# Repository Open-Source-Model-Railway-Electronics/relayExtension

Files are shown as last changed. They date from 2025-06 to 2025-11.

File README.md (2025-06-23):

# Relay Extension

These are general-purpose relay modules for use with DCC decoders like the [OS-Solenoid-Decoder](https://github.com/Open-Source-Model-Railway-Electronics/OS-Solenoid-Decoder).

## Variants

### SMD Version
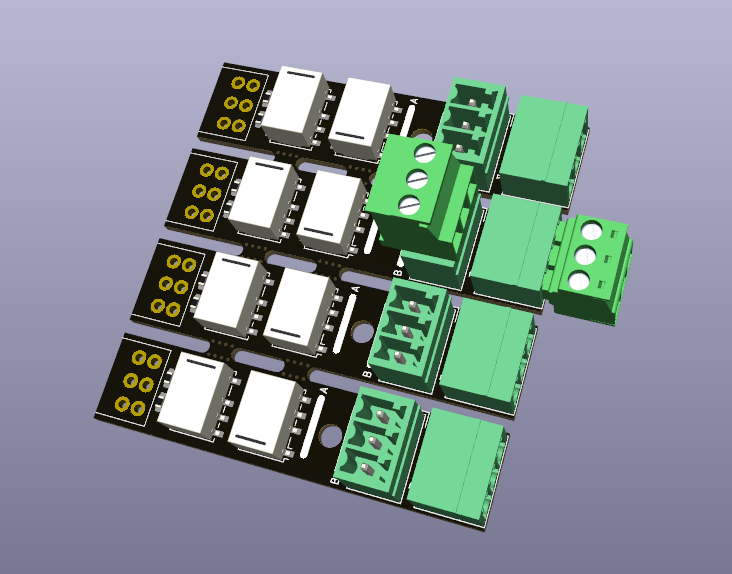
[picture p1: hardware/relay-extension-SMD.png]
SMD Relay Extension


### THT Version
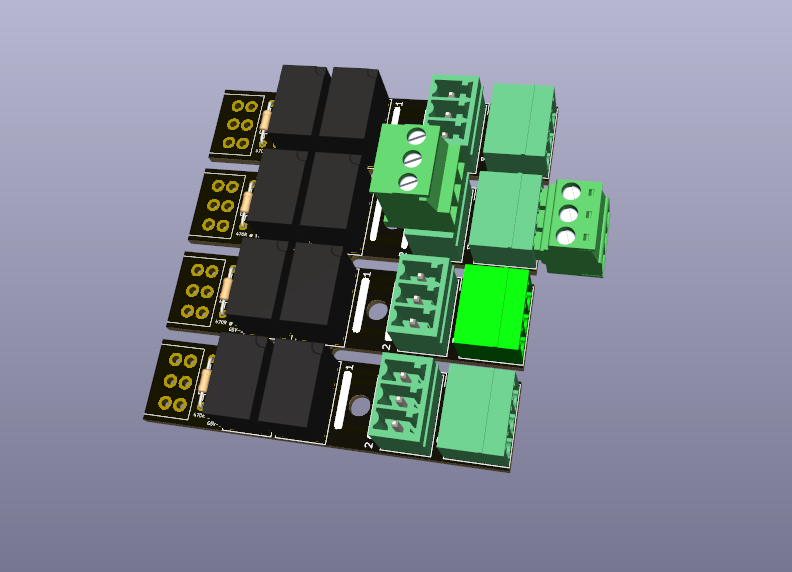
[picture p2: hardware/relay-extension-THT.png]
THT Relay Extension


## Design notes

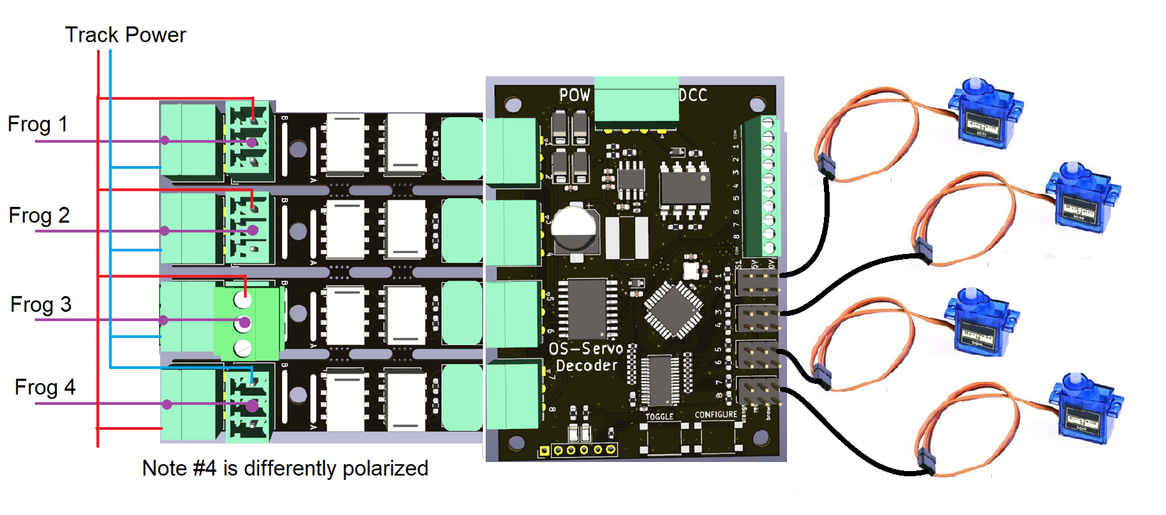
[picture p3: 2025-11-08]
docs/GP_relay_as_elekro_frog_servo.png

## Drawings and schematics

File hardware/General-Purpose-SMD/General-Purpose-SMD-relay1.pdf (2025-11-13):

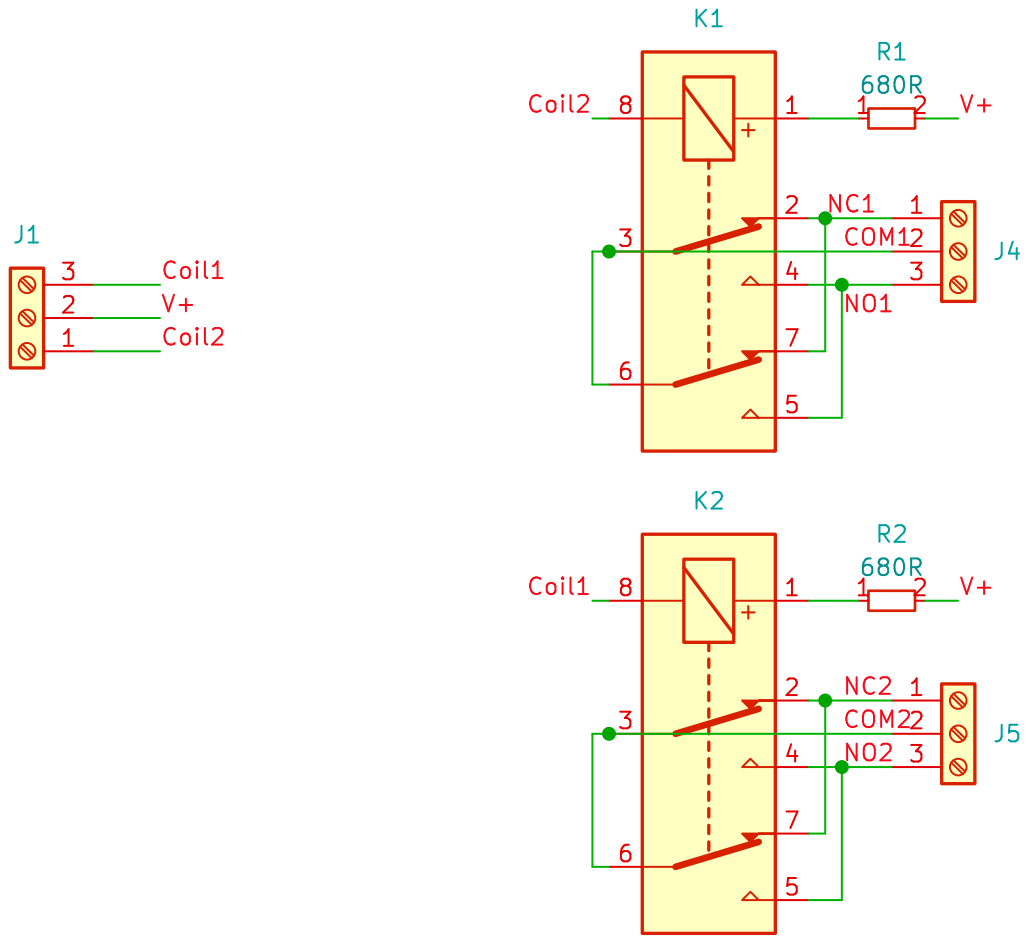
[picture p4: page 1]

Id: 2/2 Title: File: relay.kicad_sch Sheet: /relay1/ 123

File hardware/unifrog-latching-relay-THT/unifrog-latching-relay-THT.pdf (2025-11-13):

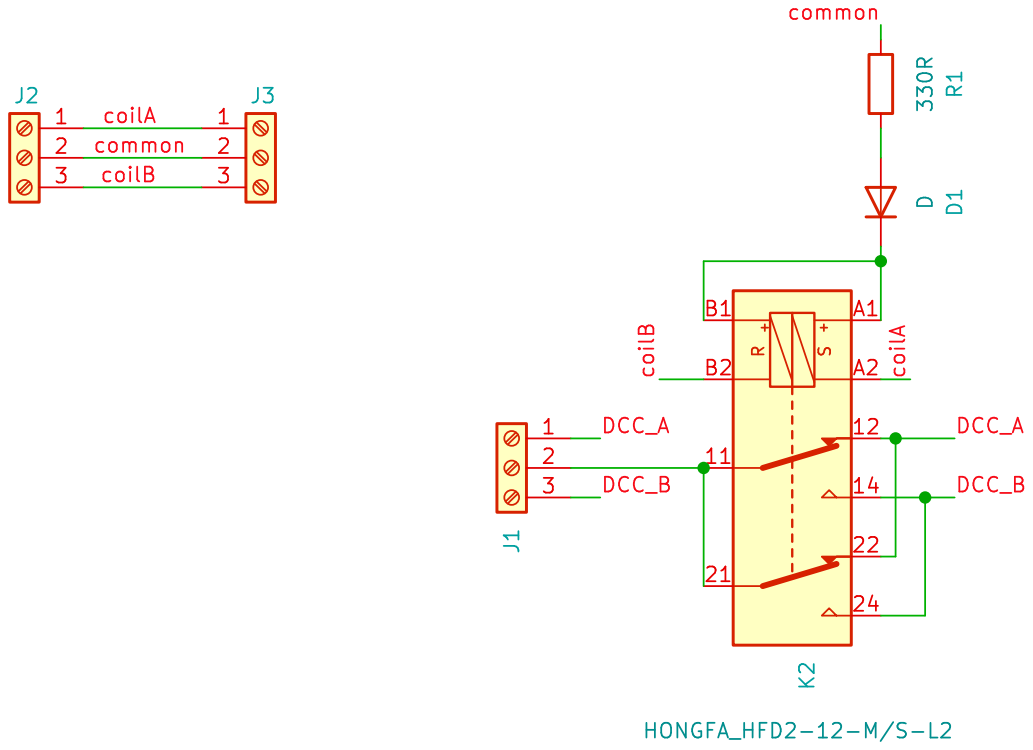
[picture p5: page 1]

Id: 1/1 Title: File: unifrog-latching-relay-THT.kicad_sch Sheet: /

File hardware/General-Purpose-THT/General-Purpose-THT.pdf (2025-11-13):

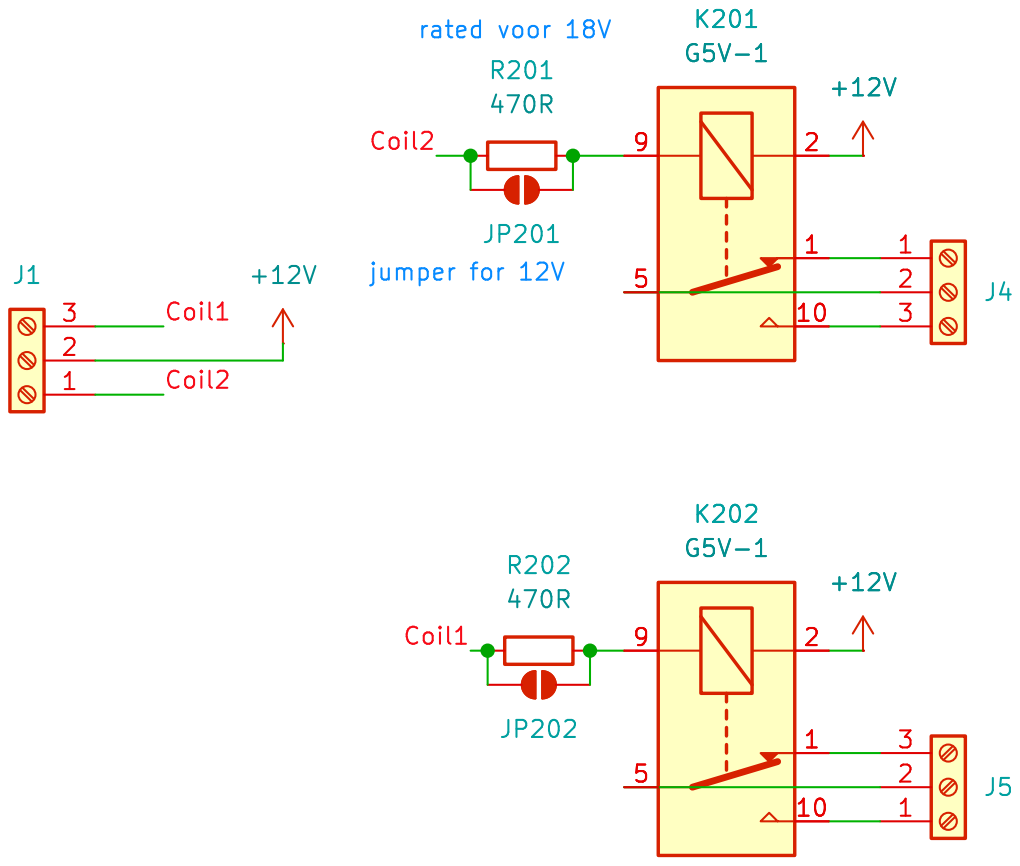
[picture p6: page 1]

Id: 2/2 Title: File: relay.kicad_sch Sheet: /relay1/

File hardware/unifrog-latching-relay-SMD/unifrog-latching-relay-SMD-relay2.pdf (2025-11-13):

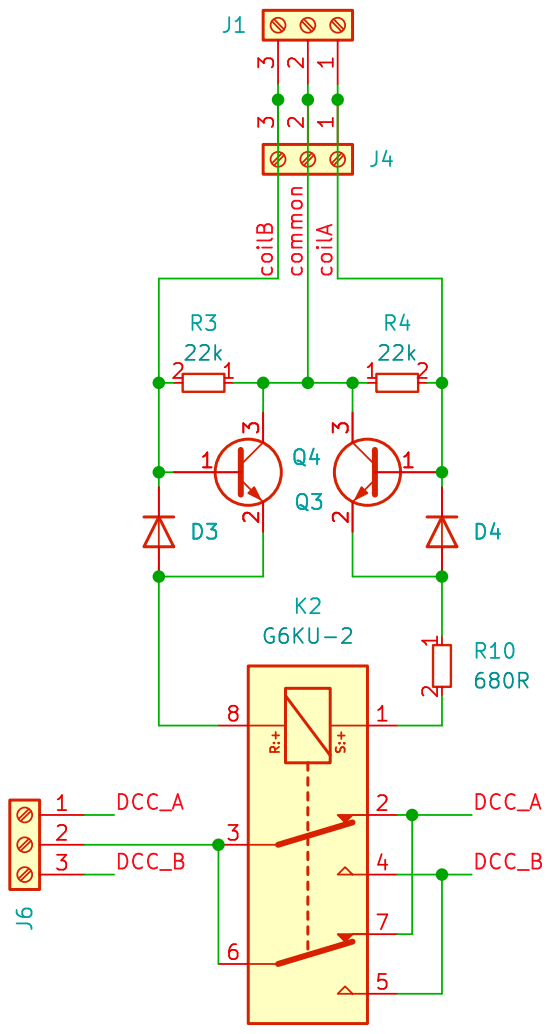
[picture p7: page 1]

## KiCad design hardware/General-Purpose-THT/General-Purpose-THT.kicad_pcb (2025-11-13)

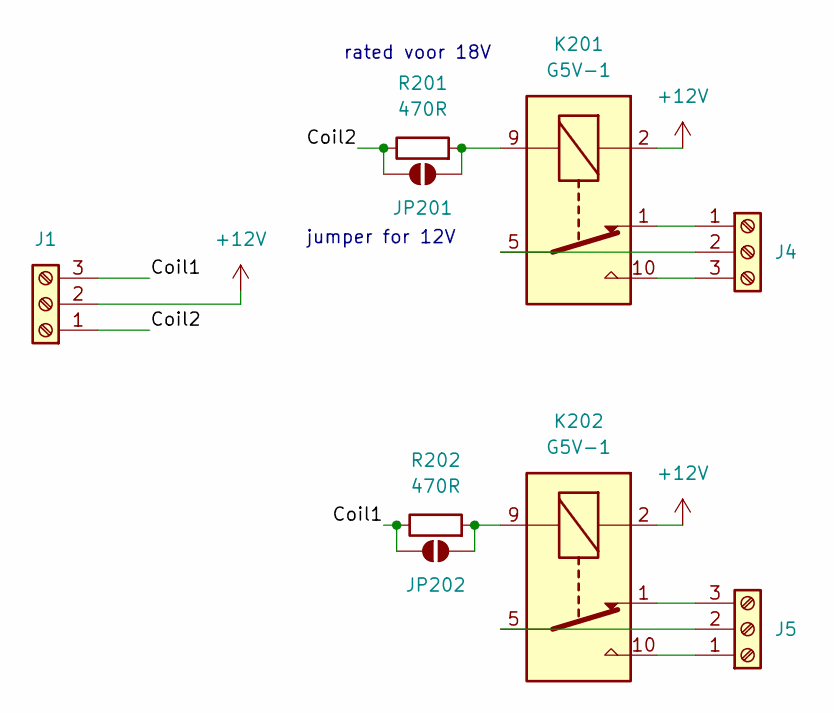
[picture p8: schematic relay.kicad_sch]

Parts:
J1: Screw_Terminal_01x03; connector_3.50mm_3P horizontal_MALE; JLCPCB Part# C6394074
J4: Screw_Terminal_01x03; PhoenixContact_MC_1,5_3-G-3.5_1x03_P3.50mm_Horizontal; JLCPCB Part# C22380440
J5: Screw_Terminal_01x03; PhoenixContact_MCV_1,5_3-G-3.5_1x03_P3.50mm_Vertical; Mating Part# C560231; JLCPCB Part# C192778
JP201, JP202: SolderJumper_2_Open; SolderJumper-2_P1.3mm_Open_RoundedPad1.0x1.5mm
K201, K202: G5V-1; Relay_SPDT_Omron_G5V-1
R201, R202: 470R; R_Axial_DIN0204_L3.6mm_D1.6mm_P7.62mm_Horizontal

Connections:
+12V: J1.2, K201.2, K202.2
/relay1/Coil1: J1.3, JP202.1 (A), R202.1
/relay1/Coil2: J1.1, JP201.1 (A), R201.1
unnamed: J4.1, K201.1
unnamed: J4.2, K201.5, K201.6
unnamed: J4.3, K201.10
unnamed: J5.1, K202.10
unnamed: J5.2, K202.5, K202.6
unnamed: J5.3, K202.1
unnamed: JP201.2 (B), K201.9, R201.2
unnamed: JP202.2 (B), K202.9, R202.2

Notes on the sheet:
jumper for 12V
rated voor 18V

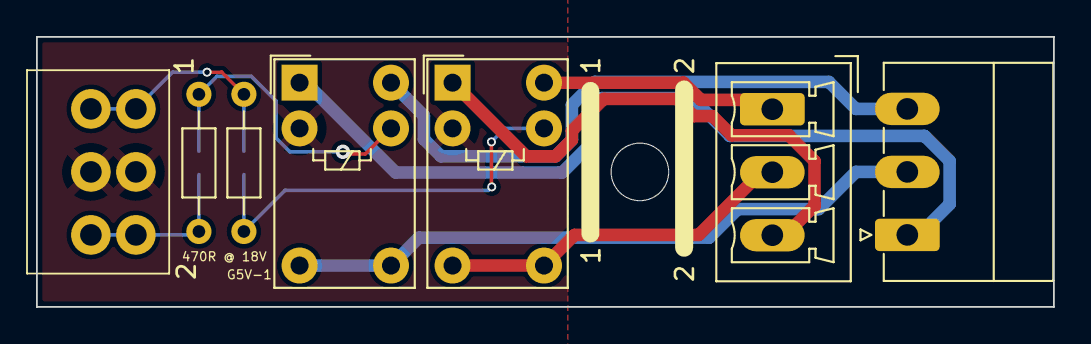
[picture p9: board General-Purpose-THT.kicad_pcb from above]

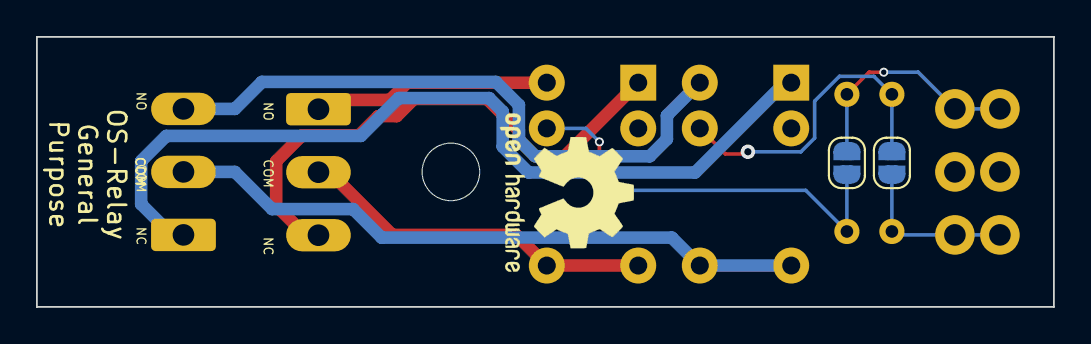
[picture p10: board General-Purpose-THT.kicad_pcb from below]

Board: 2 copper layers, 56.5 x 15.0 mm, 9 parts (2 on the bottom side), 11 nets.

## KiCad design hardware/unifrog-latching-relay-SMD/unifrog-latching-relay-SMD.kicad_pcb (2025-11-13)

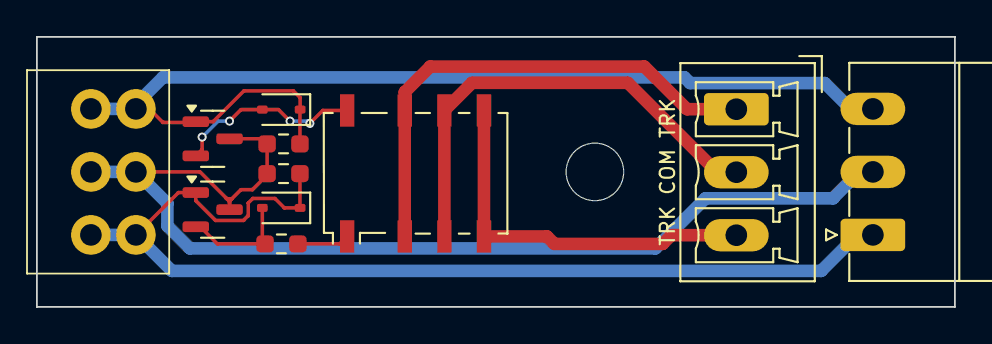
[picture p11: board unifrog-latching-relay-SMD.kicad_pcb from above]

Board: 2 copper layers, 51.0 x 15.0 mm, 11 parts (0 on the bottom side), 9 nets.

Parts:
D3, D4: 1N4148WS; D_SOD-323
J1: Screw_Terminal_01x03; connector_3.50mm_3P horizontal_MALE
J4: Screw_Terminal_01x03; PhoenixContact_MC_1,5_3-G-3.5_1x03_P3.50mm_Horizontal
J6: Screw_Terminal_01x03; PhoenixContact_MCV_1,5_3-G-3.5_1x03_P3.50mm_Vertical
K2: G6KU-2; Relay_DPDT_Omron_G6K-2F-Y
Q3, Q4: NPN_TOR; SOT-23
R3, R4: 22k; R_0603_smalltext
R10: 680R; R_0603_smalltext

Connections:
/relay2/DCC_A: J6.1, K2.2, K2.7
/relay2/DCC_B: J6.3, K2.4, K2.5
/relay2/coilA: D4.1 (K), J1.1, J4.1, Q4.1 (B), R4.2
/relay2/coilB: D3.1 (K), J1.3, J4.3, Q3.1 (B), R3.2
/relay2/common: J1.2, J4.2, Q3.3 (C), Q4.3 (C), R3.1, R4.1
unnamed: D3.2 (A), K2.8, Q3.2 (E)
unnamed: D4.2 (A), Q4.2 (E), R10.1
unnamed: J6.2, K2.3, K2.6
unnamed: K2.1, R10.2

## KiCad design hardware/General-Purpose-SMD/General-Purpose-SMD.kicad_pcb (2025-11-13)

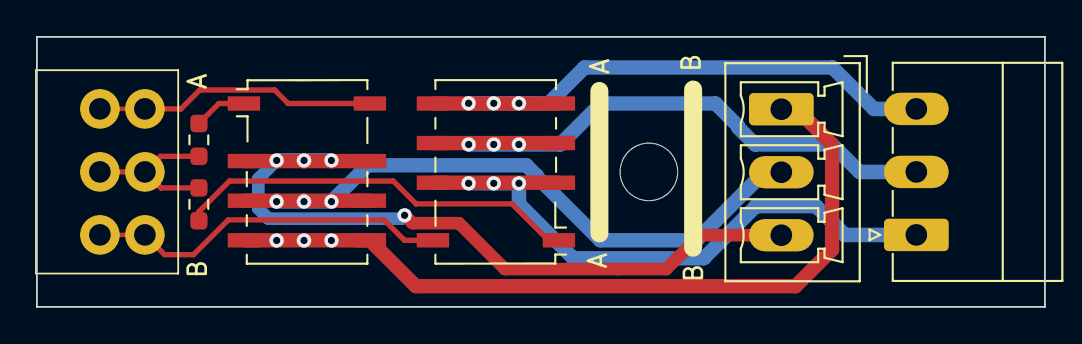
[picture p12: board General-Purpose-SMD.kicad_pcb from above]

Board: 2 copper layers, 56.0 x 15.0 mm, 7 parts (0 on the bottom side), 11 nets.

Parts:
J1: Screw_Terminal_01x03; connector_3.50mm_3P horizontal_MALE
J4: Screw_Terminal_01x03; PhoenixContact_MC_1,5_3-G-3.5_1x03_P3.50mm_Horizontal
J5: Screw_Terminal_01x03; PhoenixContact_MCV_1,5_3-G-3.5_1x03_P3.50mm_Vertical
K1, K2: G6K-2F-Y-TR DC12; Relay_DPDT_Omron_G6K-2F-Y
R1, R2: 680R; R_0603_smalltext

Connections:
/relay1/COM1: J4.2, K1.3, K1.6
/relay1/COM2: J5.2, K2.3, K2.6
/relay1/Coil1: J1.3, K2.8
/relay1/Coil2: J1.1, K1.8
/relay1/NC1: J4.1, K1.2, K1.7
/relay1/NC2: J5.3, K2.2, K2.7
/relay1/NO1: J4.3, K1.4, K1.5
/relay1/NO2: J5.1, K2.4, K2.5
/relay1/V+: J1.2, R1.2, R2.2
unnamed: K1.1, R1.1
unnamed: K2.1, R2.1

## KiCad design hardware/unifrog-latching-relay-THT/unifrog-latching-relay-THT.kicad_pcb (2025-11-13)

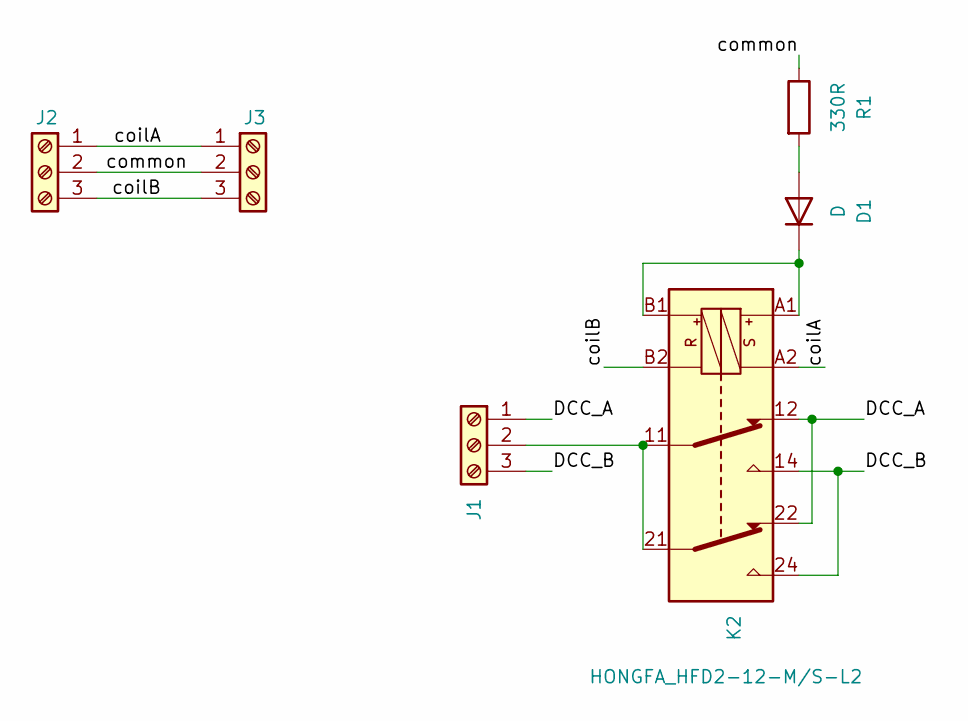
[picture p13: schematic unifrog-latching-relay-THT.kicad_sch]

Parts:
D1: D; D_DO-34_SOD68_P7.62mm_Horizontal
J1: Screw_Terminal_01x03; PhoenixContact_MCV_1,5_3-G-3.5_1x03_P3.50mm_Vertical; mating part# C560231; JLCPCB Part# C880555
J2: Screw_Terminal_01x03; connector_3.50mm_3P horizontal_MALE; JLCPCB Part# C6394074
J3: Screw_Terminal_01x03; PhoenixContact_MC_1,5_3-G-3.5_1x03_P3.50mm_Horizontal; Mating Part# C560213; JLCPCB Part# C880573
K2: HONGFA_HFD2-12-M/S-L2; Relay_DPDT_Omron_G6AK
R1: 330R; R_Axial_DIN0204_L3.6mm_D1.6mm_P7.62mm_Horizontal

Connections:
/DCC_A: J1.1, K2.12, K2.22
/DCC_B: J1.3, K2.14, K2.24
/coilA: J2.1, J3.1, K2.A2
/coilB: J2.3, J3.3, K2.B2
/common: J2.2, J3.2, R1.1
unnamed: D1.2 (A), R1.2
unnamed: D1.1 (K), K2.A1, K2.B1
unnamed: J1.2, K2.11, K2.21

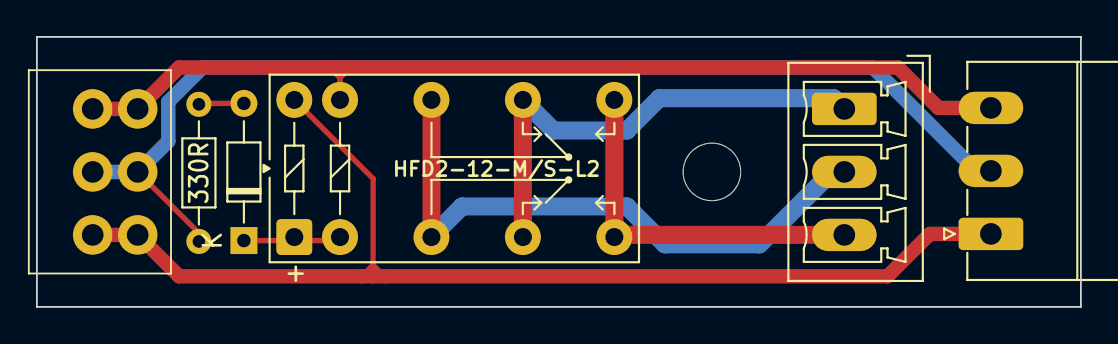
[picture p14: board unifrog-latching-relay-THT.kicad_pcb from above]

Board: 2 copper layers, 58.0 x 15.0 mm, 6 parts (0 on the bottom side), 8 nets.

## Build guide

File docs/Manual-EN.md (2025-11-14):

# OS Relay Modules Manual

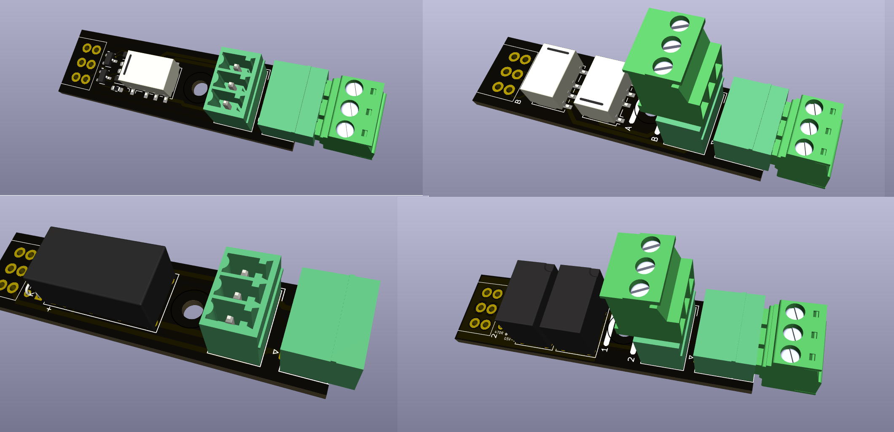
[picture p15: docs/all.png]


## Introduction

This document describes the OS relay modules used in Open Source Model
Railway Electronics projects: - **OS-General-Purpose-Relay** (dual relay
module) - **OS-Latching-Relay** (single bistable relay module)

Both relay types exist in **THT** and **SMD** versions and can be
plugged directly into OS decoders or be used standalone.

------------------------------------------------------------------------

## 1. OS-General-Purpose-Relay

The OS-General-Purpose-Relay module contains **two mono stable relays**,
each with: - **1× Common (COM)** - **1× Normally Open (NO)** - **1×
Normally Closed (NC)**


*Contacts of General Purpose Relays*

### Features

-   Compatible with **OS-Solenoid-Decoder** and **OS-Servo-Decoder**
-   Suitable for:
    -   Accessory switching (lights, signals, animations)
    -   **Electrofrog** turnout frog polarization
    -   **Unifrog** turnout frog polarization
    -   **Power routing sidings**

### Example Use Cases

-   Switching power to isolated track sections
-   Creating automated frog polarity switching
-   Controlling external electronics such as LEDs, bells, or motors
-   Power‑routing turnout configurations

------------------------------------------------------------------------

## 2. OS-Latching-Relay

The OS-Latching-Relay is a **single bistable (latching) relay**.\
It **remains in its last position without continuous power**.




### Important Notes

-   Cannot be used for **electrofrog** turnouts\
    (electrofrog requires a continuous, non‑latching polarity change)
-   Works perfectly with **unifrog** turnouts
-   The relay coil can be connected **in parallel** with the turnout
    solenoid coil, it does not require extra decoders

### Use Cases with DCC Decoders

-   **Unifrog frog polarization**
-   Self‑thinking turnouts / power‑routing
-   Accessory switching
-   Standalone operation with any solenoid decoder

------------------------------------------------------------------------

## 3. Using the Relays with OS Decoders

### With OS-Solenoid-Decoder

-   Supports both:
    -   OS-General-Purpose-Relay\
    -   OS-Latching-Relay (for unifrog only)

### With OS-Servo-Decoder

-   Supports only:
    -   **OS-General-Purpose-Relay**
-   Typical uses:
    -   Frog polarity switching
    -   Accessory switching

------------------------------------------------------------------------

## 4. Standalone Usage

Both relay modules can be used without OS decoders.

### Requirements

-   A 5V logic-level control signal
-   Power supply appropriate to the relay type
-   Any microcontroller, Arduino, or third‑party decoder capable of
    driving a small relay

### Typical Standalone Applications

-   Switching LEDs or signals
-   Power routing in sidings
-   Controlling frog polarity in turnout modules
-   Low‑current automation tasks

------------------------------------------------------------------------

## Summary Table

## Summary Table

| Relay Type | Unifrog | Electrofrog | Accessory Switching | Self-Thinking Sidings | Works With |
|---|---|---|---|---|---|
| **OS-General-Purpose-Relay** | ✔ | ✔ | ✔ | ✔ | Servo + Solenoid Decoders |
| **OS-Latching-Relay** | ✔ | ✖ | ✔ | ✔ | Solenoid Decoders Only |

------------------------------------------------------------------------

## Wiring Examples

Illustrations of typical wiring setups can be found in the project
repository and the OS decoder manuals.

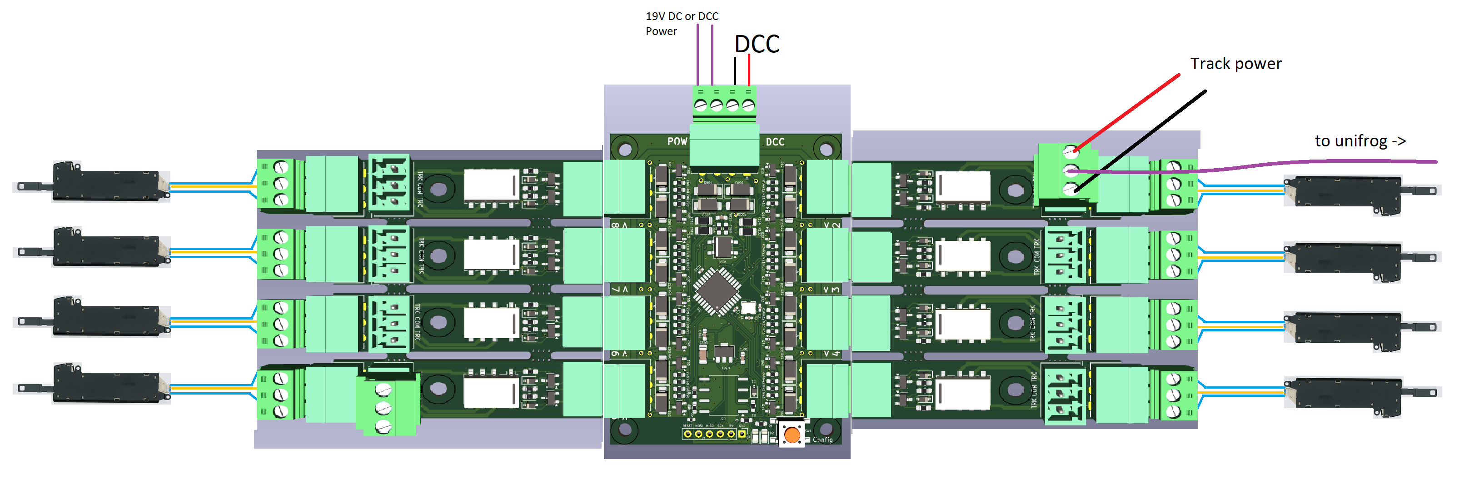
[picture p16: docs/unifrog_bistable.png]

*OS-Solenoid decoder with 8 OS-latching-relays plugged in*

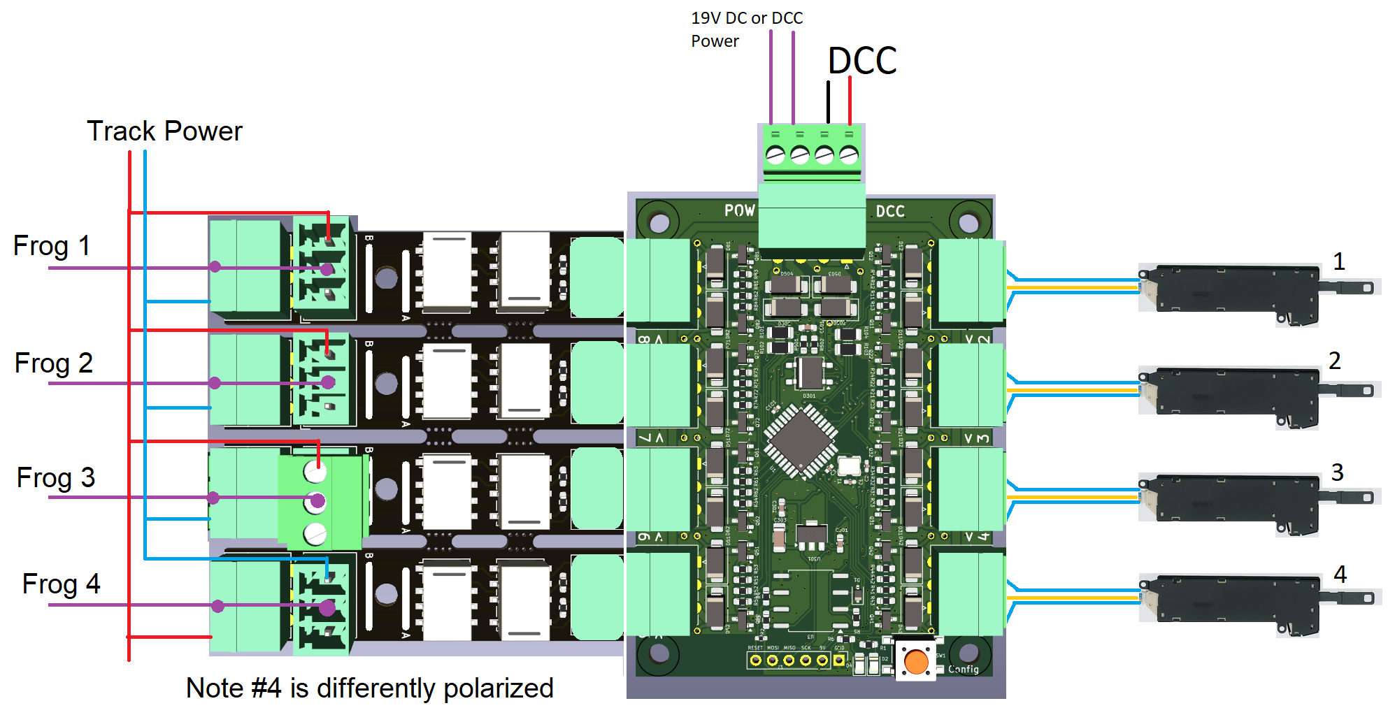
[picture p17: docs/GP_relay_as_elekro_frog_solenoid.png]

*OS-General-Purpose relay wired to OS-Solenoid-Decoder for electrofrog points*

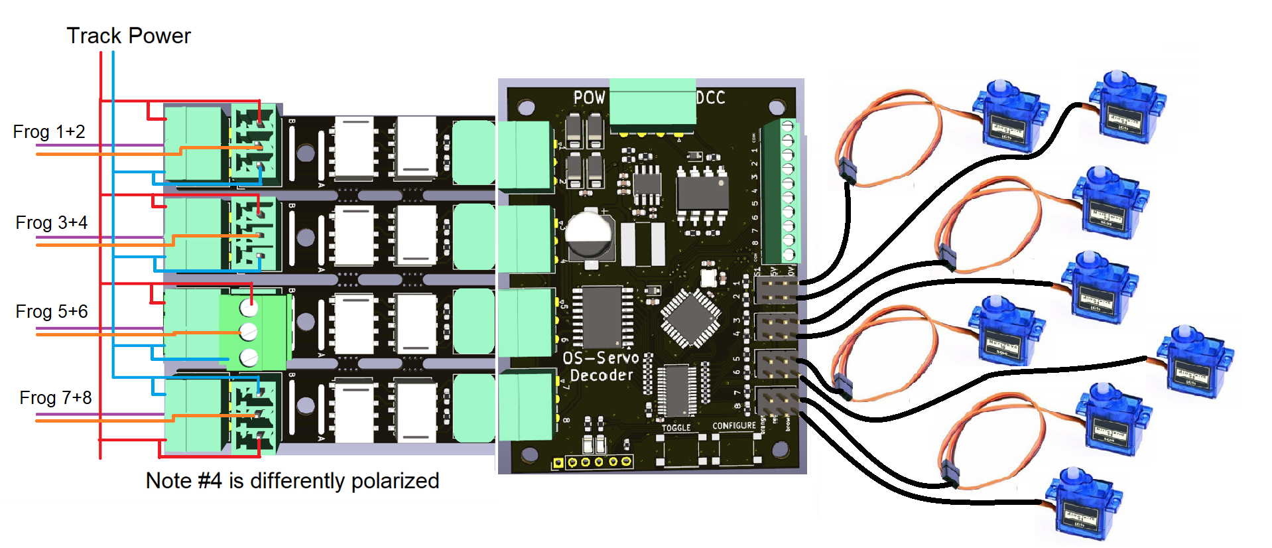
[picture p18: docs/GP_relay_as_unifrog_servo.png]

*OS-General-Purpose relay connected to OS-Servo-Decoder for unifrog points*


*OS-General-Purpose relay connected to OS-Servo-Decoder for electrofrog points*

## 5. Additional PCB ordering instructions

All OS-Relays have been designed so they can be ordered in so called panels. When they are ordered in panels, they have the same distances as the OS-decoder sockets. The PCBs can also be ordered as loose separated units, but as panels the PCBs are cheaper per unit.

To order them as a panel. You need to click on **Panel by JLCPCB** behind **Delivery format**. This will open a new window where you have to set the amount of colomns and rows. There are 2 rules:

- JLCPCB demands that panels need to be bigger than 70x70mm, the relays are around 50mm long and 15mm wide. 
- If they are to be used in combination with OS Solenoid or servo decoders. You want to have groups of 4 units, though this is not mandatory.

To meet the first demand you need atleast panels of 2 rows and 5 columns. To meet the second demand I recommend to increase to 8 colums. This essentially gives you 4 sets.

Whether you should order panels or loose PCBs also depends on how much you want. The minimum order amount is 5 units. So this can be 5 relays or it can be 5 panels of 10 - 16 relay modules each. You can always examine the price with shipping in the last cost, before paying. So you can stop your order at anytime. 



For further instruction about ordering PCBs look [here](https://github.com/Open-Source-Model-Railway-Electronics/docs/blob/master/Ordering_bare_PCB/Ordering_bare_PCB-EN.md) for bare boards and [here](https://github.com/Open-Source-Model-Railway-Electronics/docs/blob/master/Ordering_SMT_ASSEMBLED_PCB/Ordering_Assembled_PCBs_JLCPCB-EN.md) for SMT assembled boards

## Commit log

2025-06-17 added all files
    [doubleRelayExtensionTHT.kicad_pcb, doubleRelayExtensionTHT.kicad_sch, relay.kicad_sch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]
2025-06-23 added data to readme.md
    [relay.kicad_sch, relayExtension.kicad_pcb, relayExtension.kicad_sch]
2025-10-27 added single variant for SMD relay to be made using V-cuts
    [doubleRelayExtensionTHT.kicad_pcb, doubleRelayExtensionTHT.kicad_sch, relay.kicad_sch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]
2025-11-13 redid the through-hole relay pcb
    [BOM-doubleRelayExtensionSMD.csv, General-Purpose-THT.kicad_pcb, General-Purpose-THT.kicad_sch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]
2025-11-13 finalized relays repo. Yet to do manual. Release is ready togo
    [General-Purpose-SMD.kicad_pcb, General-Purpose-SMD.kicad_sch, General-Purpose-THT.kicad_pcb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]
2025-11-14 Made the manual for the OS-Relays
